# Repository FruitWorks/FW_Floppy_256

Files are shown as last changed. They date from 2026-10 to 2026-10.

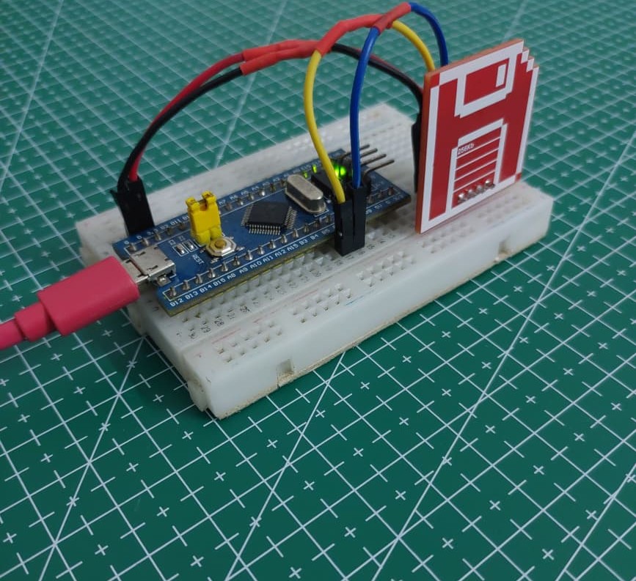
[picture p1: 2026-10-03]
images/STM32_Bluepill.jpeg

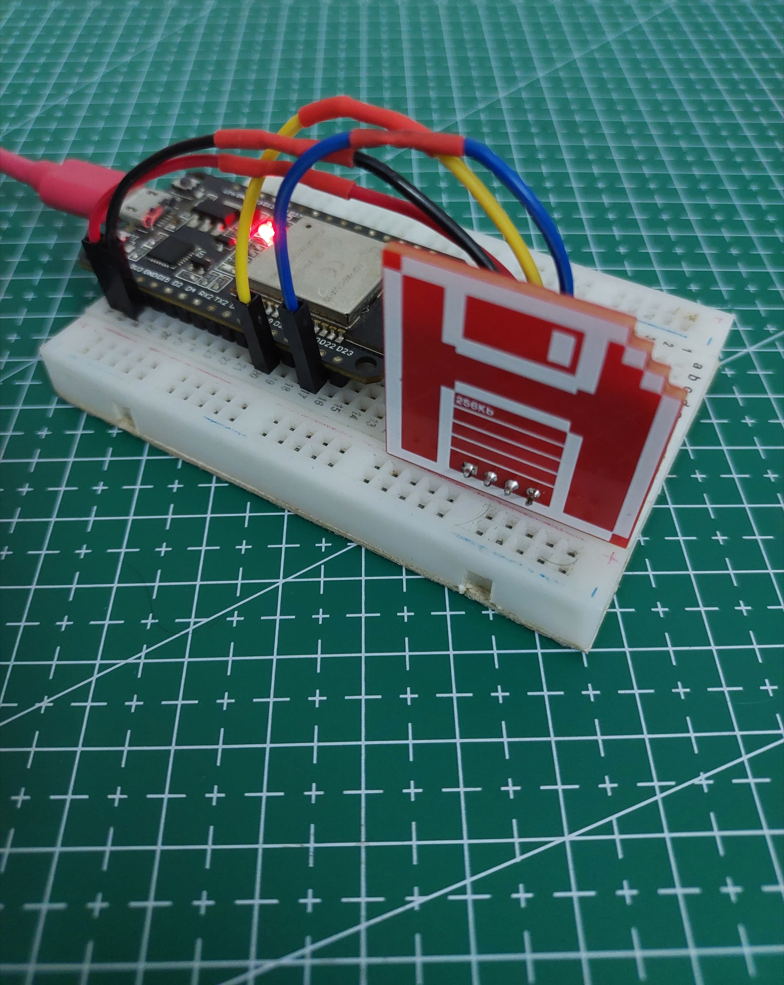
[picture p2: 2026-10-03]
images/ESP32.jpeg

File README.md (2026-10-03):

# Floppy256

A 256Kbit (32KB) I²C EEPROM shaped like a miniature 3.5" floppy disk.

Made by [FruitWorks](#).

Floppy256

floppyrear

## What it is

Floppy256 is a small I²C EEPROM module inspired by the classic 3.5" floppy disk and the familiar save icon.

The idea came from looking at generic EEPROM breakout boards and wondering why a memory module had to look like every other little PCB. I wanted to take something simple and useful and give it a bit of retro-computing personality.

It uses a 256Kbit EEPROM and provides a simple four-pin I²C interface for adding non-volatile storage to microcontroller projects.

## Specs

| | |
|---|---|
| EEPROM | ST M24256-DFMN6TP |
| Capacity | 256 Kbit / 32 KB |
| Interface | I²C |
| Default I²C Address | `0x50` |
| Address Pins | A0, A1, A2 strapped low |
| Page Size | 64 bytes |
| EEPROM Supply Voltage | 1.7V–5.5V |
| Pinout | SDA, SCL, VCC, GND |

The EEPROM address is determined by A0/A1/A2. In the current Floppy256 hardware design, these pins are tied low, giving a default address of `0x57`.

For a 3.3V microcontroller, power the module from 3.3V. For a 5V system, power it from 5V. The host MCU I²C logic level should match the module supply voltage.

Datasheet: [ST M24256-DF](https://www.st.com/en/memories/m24256-df.html)

## Pinout

| Pin | Function |
|---|---|
| SDA | I²C data |
| SCL | I²C clock |
| VCC | Power |
| GND | Ground |

## Wiring

```text
Floppy256       Microcontroller
-----------     --------------
VCC       ----> 3.3V or 5V*
GND       ----> GND
SDA       ----> I²C SDA
SCL       ----> I²C SCL
```

`*` Use a supply voltage appropriate for your MCU's I²C logic level.

The board includes the I²C pull-up resistors required for normal operation.

## Getting Started

### Arduino example

The following example writes a short message to address `0` and reads it back.

```cpp
#include <Wire.h>

#define EEPROM_ADDR 0x57

void writeEEPROM(uint16_t address, const char *text) {
  Wire.beginTransmission(EEPROM_ADDR);
  Wire.write(address >> 8);
  Wire.write(address & 0xFF);

  while (*text) {
    Wire.write(*text++);
  }

  Wire.endTransmission();
  delay(10);
}

void readEEPROM(uint16_t address, char *buffer, size_t length) {
  Wire.beginTransmission(EEPROM_ADDR);
  Wire.write(address >> 8);
  Wire.write(address & 0xFF);
  Wire.endTransmission(false);

  Wire.requestFrom(EEPROM_ADDR, (uint8_t)length);

  size_t i = 0;
  while (Wire.available() && i < length - 1) {
    buffer[i++] = Wire.read();
  }

  buffer[i] = '\0';
}

void setup() {
  Serial.begin(115200);
  Wire.begin();

  writeEEPROM(0, "Hello from Floppy256!");

  char data[32];
  readEEPROM(0, data, sizeof(data));

  Serial.println(data);
}

void loop() {
}
```

Serial Monitor output:

```text
Hello from Floppy256!
```
## Floppy256 in Action

Floppy256 works with a wide range of microcontrollers through the standard I²C interface.

RPI_Pico

Floppy256 connected to Raspberry Pi Pico

STM32_Bluepill

Floppy256 connected to STM32 Bluepill

ESP32

Floppy256 connected to ESP32 Development Boards

## Open Source / Build Your Own

Floppy256 is an open hardware project.

If you build your own Floppy256, a credit or link back to FruitWorks is appreciated.

If you make improvements or create your own version, feel free to share them.

## Manufacturing

Floppy256 was designed in KiCad and is produced in very small batches.

The design uses standard PCB manufacturing and assembly processes and commonly available components.

## License

The hardware, software, documentation, and images in this repository are intended to remain open.

See the license files included in this repository for the applicable terms.

## Credits

Designed and built by **FruitWorks**.

Floppy256 is a small independent hardware project made in very small batches.

## Get One

Floppy256 is available from [Tindie](#).

Made for makers, retro-computing fans, and anyone who thinks a floppy-shaped EEPROM is a little more fun than a generic breakout board.

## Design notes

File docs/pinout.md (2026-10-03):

# Pinout

| Pin | Function | Notes |
|---|---|---|
| SDA | I2C data | Onboard 4.7kΩ pull-up |
| SCL | I2C clock | Onboard 4.7kΩ pull-up |
| VCC | Power | 3.3 to 5V |
| GND | Ground | |

## I2C Address

Address: `0x57`

## Example wiring (Raspberry Pi Pico / RP2040)

| Pico pin | Floppy256 pin |
|---|---|
| GPIO__ | SDA |
| GPIO__ | SCL |
| GND | GND |
| 3V3_OUT | VCC |

<!-- Note which I2C hardware block (I2C0/I2C1) these GPIOs belong to -->

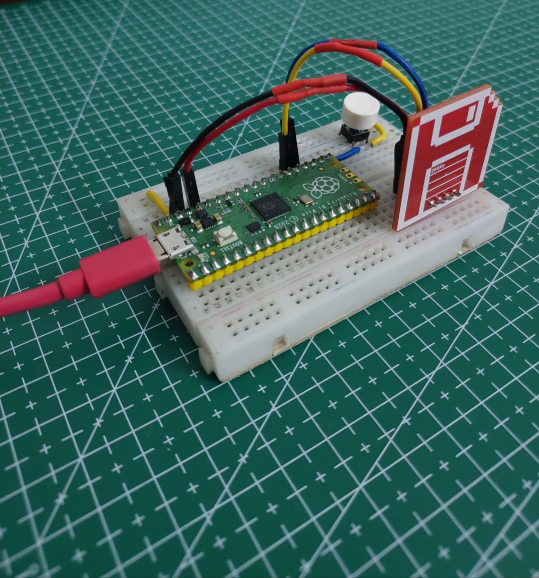
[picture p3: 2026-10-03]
images/RPI_Pico.jpeg

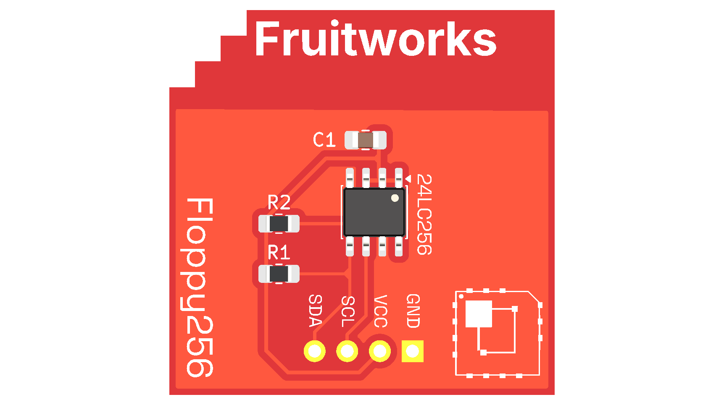
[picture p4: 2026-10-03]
images/floppyrear.png

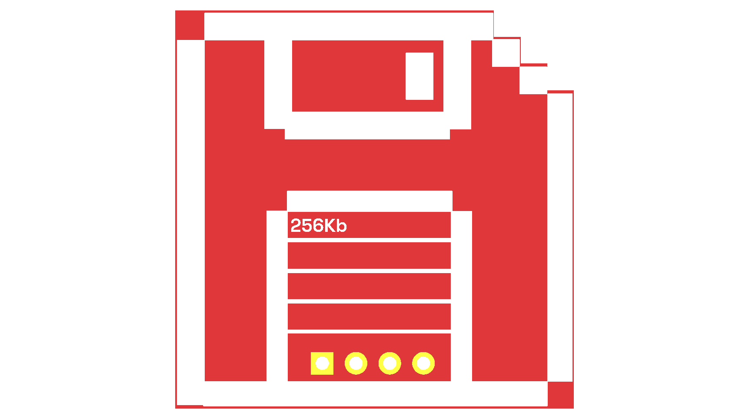
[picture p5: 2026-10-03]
images/floppyfront.png

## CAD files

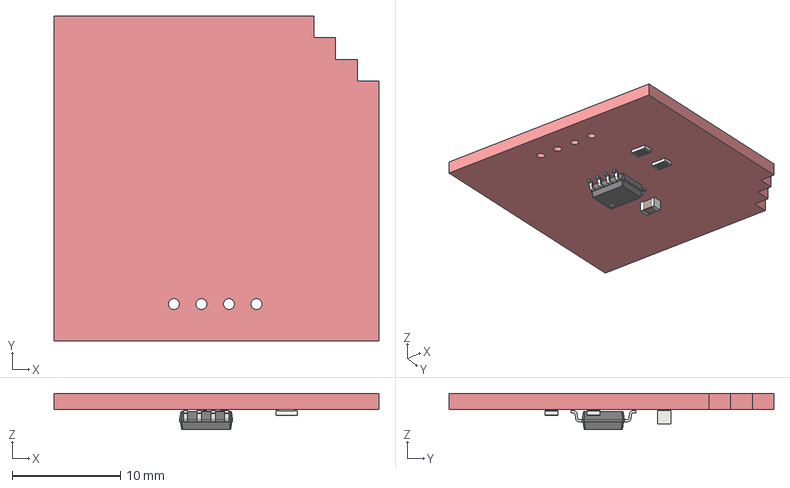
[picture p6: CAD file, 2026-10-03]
hardware/FW-Floppy256.step
30.0 x 30.0 x 3.35 mm
C_0805_2012Metric
R_0805_2012Metric x 2
SOIC-8_3.9x4.9mm_P1.27mm
FW-Floppy256-unsaved-export-XBoFN3_PCB

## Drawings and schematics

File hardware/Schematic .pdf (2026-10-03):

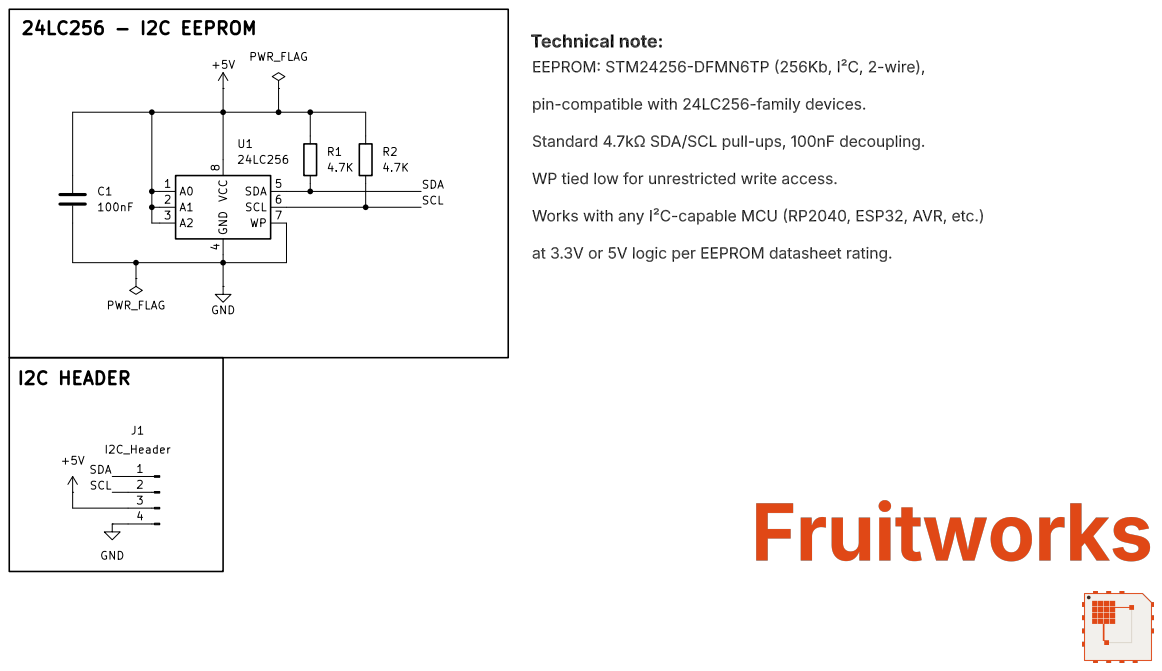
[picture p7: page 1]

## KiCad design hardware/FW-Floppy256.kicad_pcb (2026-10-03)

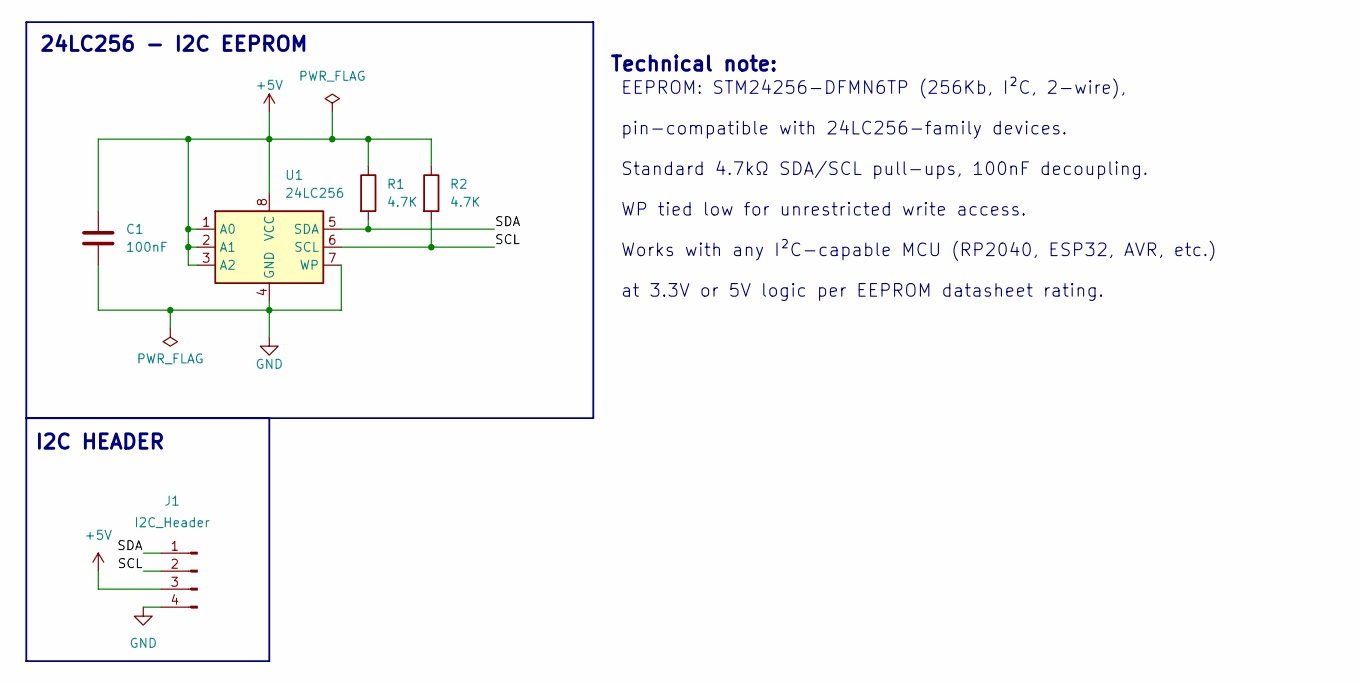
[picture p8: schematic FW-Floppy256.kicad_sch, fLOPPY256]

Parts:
C1: 100nF; C_0805_2012Metric_Pad1.18x1.45mm_HandSolder
J1: I2C_Header; PinHeader_1x04_P2.54mm_Vertical
R1, R2: 4.7K; R_0805_2012Metric_Pad1.20x1.40mm_HandSolder
U1: 24LC256; SOIC-8_3.9x4.9mm_P1.27mm

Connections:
+5V: C1.1, J1.3, R1.1, R2.1, U1.1 (A0), U1.2 (A1), U1.3 (A2), U1.8 (VCC)
/SCL: J1.2, R2.2, U1.6 (SCL)
/SDA: J1.1, R1.2, U1.5 (SDA)
GND: C1.2, J1.4, U1.4 (GND), U1.7 (WP)

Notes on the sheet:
EEPROM: STM24256-DFMN6TP (256Kb, I²C, 2-wire), pin-compatible with 24LC256-family devices. Standard 4.7kΩ SDA/SCL pull-ups, 100nF decoupling. WP tied low for unrestricted write access. Works with any I²C-capable MCU (RP2040, ESP32, AVR, etc.) at 3.3V or 5V logic per EEPROM datasheet rating.
24LC256 - I2C EEPROM
Technical note:
I2C HEADER

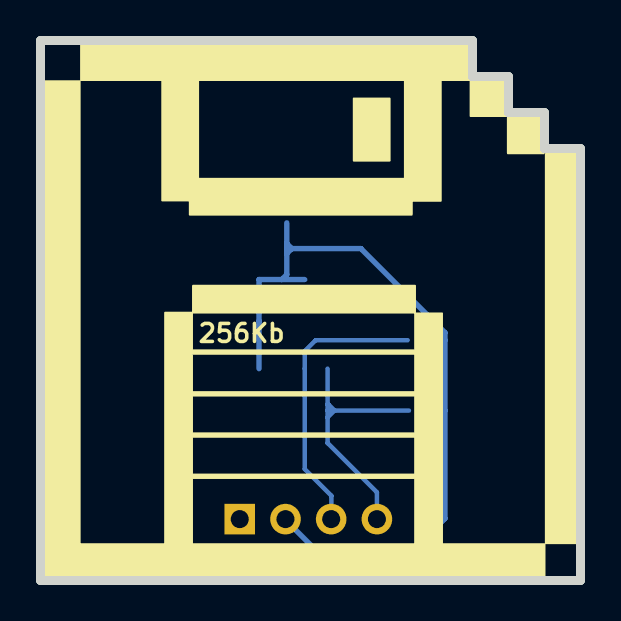
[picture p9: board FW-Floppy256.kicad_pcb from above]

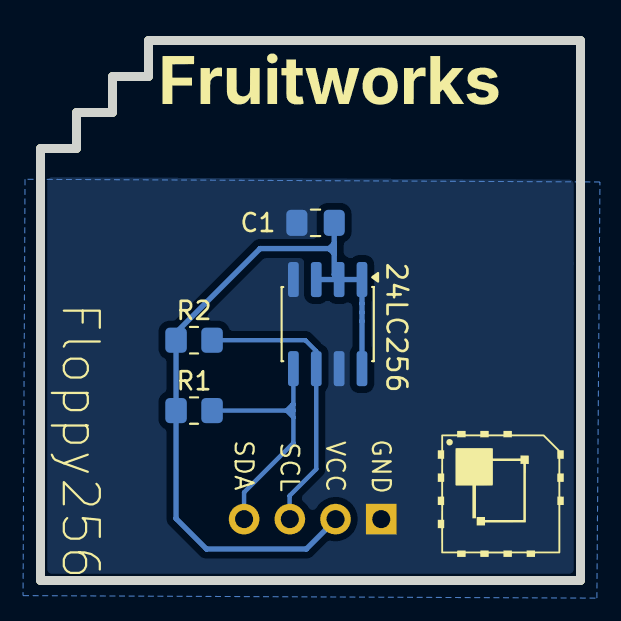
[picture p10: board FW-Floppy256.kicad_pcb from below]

Board: 2 copper layers, 30.0 x 30.0 mm, 5 parts (4 on the bottom side), 4 nets.

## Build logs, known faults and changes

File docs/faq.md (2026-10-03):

# FAQ

**Is this real storage, or just a novelty shape?**

It’s real storage. Floppy256 uses a 256Kbit (32KB) I²C EEPROM, so you can store configuration data, calibration values, settings, small logs, or other non-volatile data for your projects. The floppy shape is just our way of making a familiar component a little more interesting.

**Why no QWIIC/STEMMA connector?**

Floppy256 keeps things simple with a standard 4-pin header: **VCC, GND, SDA and SCL**. It keeps the board small and preserves the floppy-disk-inspired design without adding another connector standard.

**What's the real capacity?**

Floppy256 has **256Kbit of EEPROM**, which is **32KB (32,768 bytes)** of usable non-volatile storage.

**Can I chain multiple Floppy256 boards on one bus?**

Yes, I²C allows multiple devices on the same bus, but the current Floppy256 design has A0, A1, and A2 strapped low, so every board uses the same default address (`0x57`). Because of this, multiple standard Floppy256 boards cannot be used directly on the same bus without changing the addressing arrangement or using an I²C multiplexer.

**Does it need external pull-ups?**

No, not normally. Floppy256 already includes **4.7kΩ pull-up resistors on SDA and SCL**. Just connect it to your I²C bus and power it appropriately.

**What microcontrollers does it work with?**

Floppy256 works with most microcontrollers that support **I²C**, including platforms such as **Arduino, ESP32, ESP8266, RP2040/Pico and STM32**.

The EEPROM itself supports **1.7V–5.5V operation**. Use a supply voltage and I²C logic level that are appropriate for your microcontroller.

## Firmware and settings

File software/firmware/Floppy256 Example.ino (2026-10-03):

/*
 * Generic I2C EEPROM Test Firmware
 * For 24LC256-family EEPROMs (256Kbit / 32KB, 64-byte page, 2-byte address)
 * MCU: any Arduino-framework board with a configurable I2C port
 *
 * This is a generic hardware-bring-up test, not tied to any specific
 * product or vendor. Edit the CONFIG block below for your board's
 * wiring and I2C address, then upload.
 *
 * Works with any chip in the 24LC256 family (ST M24256, Microchip
 * 24LC256/24AA256, ON Semi CAT24C256, etc.) since they share the same
 * 32KB / 64-byte-page / 2-byte-address electrical interface.
 */

#include <Wire.h>

// ====================== CONFIG — edit for your board ======================

#define EEPROM_I2C_ADDR   0x50   // default 24LC256 address with A0/A1/A2 low.
                                  // Change if your board straps A0/A1/A2 differently.

#define USE_SECOND_I2C_BUS false // set true if your SDA/SCL pins require a
                                  // second I2C hardware block (e.g. RP2040
                                  // GPIO18/19 = I2C1, not I2C0 = Wire).
                                  // If true, this sketch uses Wire1 instead
                                  // of Wire -- check your MCU's pinout docs.

#define SDA_PIN           -1     // set to your SDA GPIO number, or -1 to use
                                  // the board's default I2C pins (no remap)
#define SCL_PIN           -1     // set to your SCL GPIO number, or -1 to use
                                  // the board's default I2C pins (no remap)

// NOTE: setSDA()/setSCL() pin remapping (used below) is available on
// RP2040 and some ESP32 cores. On AVR boards (Uno, Nano, Mega) and most
// other MCUs, I2C pins are fixed in hardware and cannot be remapped --
// leave SDA_PIN/SCL_PIN at -1 on those boards.

// ====================== Chip constants (24LC256 family) ===================

#define PAGE_SIZE         64      // bytes per write page
#define EEPROM_SIZE       32768   // 32KB total
#define WRITE_DELAY_MS    10      // datasheet max write time is 5ms, margin added
#define MAX_WRITE_RETRIES 20      // ACK-polling retry count

#if USE_SECOND_I2C_BUS
  #define I2C_PORT Wire1
#else
  #define I2C_PORT Wire
#endif

bool overallPass = true;

// ---------- Low-level EEPROM access ----------

// Write up to PAGE_SIZE bytes, MUST NOT cross a page boundary.
bool eepromWritePage(uint16_t addr, const uint8_t *data, uint8_t len) {
  if (len == 0 || len > PAGE_SIZE) return false;

  // Hard check: reject any write that would cross a page boundary
  uint16_t pageStart = addr & ~(PAGE_SIZE - 1);
  if ((uint32_t)addr + len > (uint32_t)pageStart + PAGE_SIZE) {
    Serial.print("  [ERROR] Write at 0x");
    Serial.print(addr, HEX);
    Serial.println(" would cross page boundary — aborting this write.");
    return false;
  }
  if ((uint32_t)addr + len > EEPROM_SIZE) {
    Serial.println("  [ERROR] Write exceeds EEPROM address range.");
    return false;
  }

  I2C_PORT.beginTransmission(EEPROM_I2C_ADDR);
  I2C_PORT.write((uint8_t)(addr >> 8));   // address high byte
  I2C_PORT.write((uint8_t)(addr & 0xFF)); // address low byte
  for (uint8_t i = 0; i < len; i++) {
    I2C_PORT.write(data[i]);
  }
  uint8_t result = I2C_PORT.endTransmission();
  if (result != 0) {
    Serial.print("  [ERROR] I2C write failed, code=");
    Serial.println(result);
    return false;
  }

  // ACK polling: wait for internal write cycle to finish.
  // During write cycle, EEPROM NACKs its own address.
  for (int i = 0; i < MAX_WRITE_RETRIES; i++) {
    delay(1);
    I2C_PORT.beginTransmission(EEPROM_I2C_ADDR);
    if (I2C_PORT.endTransmission() == 0) {
      delay(WRITE_DELAY_MS); // small extra margin
      return true;
    }
  }

  Serial.println("  [ERROR] Write cycle did not complete (ACK poll timeout).");
  return false;
}

bool eepromRead(uint16_t addr, uint8_t *data, uint8_t len) {
  if (len == 0 || (uint32_t)addr + len > EEPROM_SIZE) return false;

  I2C_PORT.beginTransmission(EEPROM_I2C_ADDR);
  I2C_PORT.write((uint8_t)(addr >> 8));
  I2C_PORT.write((uint8_t)(addr & 0xFF));
  if (I2C_PORT.endTransmission(false) != 0) { // repeated start, no stop
    Serial.println("  [ERROR] I2C read address-set failed.");
    return false;
  }

  uint8_t received = I2C_PORT.requestFrom((uint8_t)EEPROM_I2C_ADDR, len);
  if (received != len) {
    Serial.print("  [ERROR] Requested ");
    Serial.print(len);
    Serial.print(" bytes, got ");
    Serial.println(received);
    return false;
  }

  for (uint8_t i = 0; i < len; i++) {
    data[i] = I2C_PORT.read();
  }
  return true;
}

// ---------- Test routines ----------

bool testLocation(uint16_t addr, uint8_t testLen) {
  Serial.print("Testing address 0x");
  if (addr < 0x1000) Serial.print("0");
  if (addr < 0x100) Serial.print("0");
  if (addr < 0x10) Serial.print("0");
  Serial.print(addr, HEX);
  Serial.print(" (");
  Serial.print(testLen);
  Serial.println(" bytes)...");

  // Build a deterministic, address-dependent pattern (avoids false pass
  // from a stuck-at-0x00 or stuck-at-0xFF bus/chip fault)
  uint8_t writeBuf[PAGE_SIZE];
  for (uint8_t i = 0; i < testLen; i++) {
    writeBuf[i] = (uint8_t)((addr + i) ^ 0xA5);
  }

  if (!eepromWritePage(addr, writeBuf, testLen)) {
    Serial.println("  -> FAIL (write)");
    return false;
  }

  uint8_t readBuf[PAGE_SIZE];
  if (!eepromRead(addr, readBuf, testLen)) {
    Serial.println("  -> FAIL (read)");
    return false;
  }

  for (uint8_t i = 0; i < testLen; i++) {
    if (readBuf[i] != writeBuf[i]) {
      Serial.print("  [MISMATCH] offset ");
      Serial.print(i);
      Serial.print(" wrote 0x");
      Serial.print(writeBuf[i], HEX);
      Serial.print(" read 0x");
      Serial.println(readBuf[i], HEX);
      Serial.println("  -> FAIL (data mismatch)");
      return false;
    }
  }

  Serial.println("  -> PASS");
  return true;
}

bool testSequentialBlock() {
  // One full page, sequential pattern, at an address not used by the spot tests.
  const uint16_t addr = 0x2000;
  Serial.println("Running sequential 64-byte page test at 0x2000...");

  uint8_t writeBuf[PAGE_SIZE];
  for (int i = 0; i < PAGE_SIZE; i++) {
    writeBuf[i] = (uint8_t)i;
  }

  if (!eepromWritePage(addr, writeBuf, PAGE_SIZE)) {
    Serial.println("  -> FAIL (write)");
    return false;
  }

  uint8_t readBuf[PAGE_SIZE];
  if (!eepromRead(addr, readBuf, PAGE_SIZE)) {
    Serial.println("  -> FAIL (read)");
    return false;
  }

  for (int i = 0; i < PAGE_SIZE; i++) {
    if (readBuf[i] != writeBuf[i]) {
      Serial.print("  [MISMATCH] offset ");
      Serial.println(i);
      Serial.println("  -> FAIL (data mismatch)");
      return false;
    }
  }

  Serial.println("  -> PASS");
  return true;
}

// ---------- Setup / Loop ----------

void setup() {
  Serial.begin(115200);
  while (!Serial) { delay(10); } // wait for USB serial, harmless if none

  delay(1000);
  Serial.println("=================================");
  Serial.println("Generic 24LC256-family EEPROM Test");
  Serial.println("=================================");

#if SDA_PIN >= 0 && SCL_PIN >= 0
  I2C_PORT.setSDA(SDA_PIN);
  I2C_PORT.setSCL(SCL_PIN);
#endif
  I2C_PORT.begin();
  I2C_PORT.setClock(100000); // 100kHz standard mode, safest for test jigs

  // --- Step 1: Presence check ---
  Serial.print("\n[1] Scanning for EEPROM at 0x");
  Serial.print(EEPROM_I2C_ADDR, HEX);
  Serial.println("...");
  I2C_PORT.beginTransmission(EEPROM_I2C_ADDR);
  uint8_t scanResult = I2C_PORT.endTransmission();

  if (scanResult != 0) {
    Serial.println("EEPROM NOT detected.");
    Serial.println("Check: VCC, GND, SDA/SCL wiring, address pin strapping, solder joints.");
    overallPass = false;
  } else {
    Serial.println("EEPROM detected.");

    // --- Step 2: Spot address tests ---
    Serial.println("\n[2] Running spot read/write tests...");
    overallPass &= testLocation(0x0000, 8);
    overallPass &= testLocation(0x0010, 8);
    overallPass &= testLocation(0x0100, 8);
    overallPass &= testLocation(0x1000, 8);
    overallPass &= testLocation(0x7FFF, 1); // last valid byte — single-byte only

    // --- Step 3: Sequential page test ---
    Serial.println("\n[3] Running sequential block test...");
    overallPass &= testSequentialBlock();
  }

  // --- Final verdict ---
  Serial.println("\n=================================");
  if (overallPass) {
    Serial.println("EEPROM TEST: PASS");
  } else {
    Serial.println("EEPROM TEST: FAIL");
  }
  Serial.println("=================================");
}

void loop() {
  // Nothing to do — test runs once in setup().
  // Re-power or reset the board to test the next unit.
}

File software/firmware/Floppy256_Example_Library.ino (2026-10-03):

/*
 * FruitWorks Floppy256 — Manufacturing Test (library-based)
 * MCU: Raspberry Pi Pico (RP2040), Arduino framework
 *
 * This version uses the FruitWorks_Floppy256 library instead of
 * duplicating raw I2C read/write logic -- the library already handles
 * page-boundary splitting and write-cycle ACK polling, so this sketch
 * only has to drive the test sequence and report PASS/FAIL.
 *
 * REQUIRES: FruitWorks_Floppy256 library installed
 * (Sketch -> Include Library -> Add .ZIP Library...)
 *
 * Wiring:
 *   Pico GPIO18  -> Floppy256 SDA
 *   Pico GPIO19  -> Floppy256 SCL
 *   Pico GND     -> Floppy256 GND
 *   Pico VBUS(5V)-> Floppy256 VCC
 *
 * IMPORTANT: GPIO18/19 on RP2040 belong to the I2C1 hardware block, not
 * I2C0 -- this sketch uses Wire1 for that reason.
 */

#include <Wire.h>
#include "FruitWorks_Floppy256.h"

#define SDA_PIN 18
#define SCL_PIN 19

Floppy256 myFloppy;
bool overallPass = true;

// ---------- Test routines ----------

bool testLocation(uint16_t addr, uint8_t testLen) {
  Serial.print("Testing address 0x");
  if (addr < 0x1000) Serial.print("0");
  if (addr < 0x100) Serial.print("0");
  if (addr < 0x10) Serial.print("0");
  Serial.print(addr, HEX);
  Serial.print(" (");
  Serial.print(testLen);
  Serial.println(" bytes)...");

  // Deterministic, address-dependent pattern -- avoids a false pass from
  // a stuck-at-0x00 or stuck-at-0xFF bus/chip fault.
  uint8_t writeBuf[64];
  for (uint8_t i = 0; i < testLen; i++) {
    writeBuf[i] = (uint8_t)((addr + i) ^ 0xA5);
  }

  if (!myFloppy.writeBlock(addr, writeBuf, testLen)) {
    Serial.println("  -> FAIL (write)");
    return false;
  }

  uint8_t readBuf[64];
  if (!myFloppy.readBlock(addr, readBuf, testLen)) {
    Serial.println("  -> FAIL (read)");
    return false;
  }

  for (uint8_t i = 0; i < testLen; i++) {
    if (readBuf[i] != writeBuf[i]) {
      Serial.print("  [MISMATCH] offset ");
      Serial.print(i);
      Serial.print(" wrote 0x");
      Serial.print(writeBuf[i], HEX);
      Serial.print(" read 0x");
      Serial.println(readBuf[i], HEX);
      Serial.println("  -> FAIL (data mismatch)");
      return false;
    }
  }

  Serial.println("  -> PASS");
  return true;
}

bool testSequentialBlock() {
  const uint16_t addr = 0x2000;
  const uint8_t len = 64; // one full page
  Serial.println("Running sequential 64-byte page test at 0x2000...");

  uint8_t writeBuf[len];
  for (int i = 0; i < len; i++) {
    writeBuf[i] = (uint8_t)i;
  }

  if (!myFloppy.writeBlock(addr, writeBuf, len)) {
    Serial.println("  -> FAIL (write)");
    return false;
  }

  uint8_t readBuf[len];
  if (!myFloppy.readBlock(addr, readBuf, len)) {
    Serial.println("  -> FAIL (read)");
    return false;
  }

  for (int i = 0; i < len; i++) {
    if (readBuf[i] != writeBuf[i]) {
      Serial.print("  [MISMATCH] offset ");
      Serial.println(i);
      Serial.println("  -> FAIL (data mismatch)");
      return false;
    }
  }

  Serial.println("  -> PASS");
  return true;
}

// ---------- Setup / Loop ----------

void setup() {
  Serial.begin(115200);
  while (!Serial) { delay(10); }

  delay(1000);
  Serial.println("=================================");
  Serial.println("FruitWorks Floppy256 Production Test (library-based)");
  Serial.println("=================================");

  Wire1.setSDA(SDA_PIN);
  Wire1.setSCL(SCL_PIN);
  Wire1.begin();
  Wire1.setClock(100000);

  Serial.println("\n[1] Connecting to Floppy256 at 0x57...");
  if (!myFloppy.begin(Wire1)) {
    Serial.println("Floppy256 EEPROM NOT detected.");
    Serial.println("Check: VCC, GND, SDA/SCL wiring, solder joints on U1.");
    overallPass = false;
  } else {
    Serial.println("Floppy256 EEPROM detected.");

    Serial.println("\n[2] Running spot read/write tests...");
    overallPass &= testLocation(0x0000, 8);
    overallPass &= testLocation(0x0010, 8);
    overallPass &= testLocation(0x0100, 8);
    overallPass &= testLocation(0x1000, 8);
    overallPass &= testLocation(0x7FFF, 1); // last valid byte -- single-byte only

    Serial.println("\n[3] Running sequential block test...");
    overallPass &= testSequentialBlock();
  }

  Serial.println("\n=================================");
  if (overallPass) {
    Serial.println("FLOPPY256 TEST: PASS");
  } else {
    Serial.println("FLOPPY256 TEST: FAIL");
  }
  Serial.println("=================================");
}

void loop() {
  // Nothing to do -- test runs once in setup().
  // Re-power or reset the Pico to test the next board.
}

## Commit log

2026-10-03 Update VCC voltage range in pinout documentation
2026-10-03 Update FAQ with Floppy256 details
    Added detailed answers to common questions about Floppy256 storage, including capacity, microcontroller compatibility, and design choices.
